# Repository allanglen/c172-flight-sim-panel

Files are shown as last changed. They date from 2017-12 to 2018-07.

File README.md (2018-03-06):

# Cessna 172 Skyhawk Flight Simulator Panel

 

I’m building a desk-mounted Cessna 172 flight simulator instrument panel for use as a training device in conjunction with real-world flight training. 

For details visit the project site at [https://cessna172sim.allanglen.com](https://cessna172sim.allanglen.com)

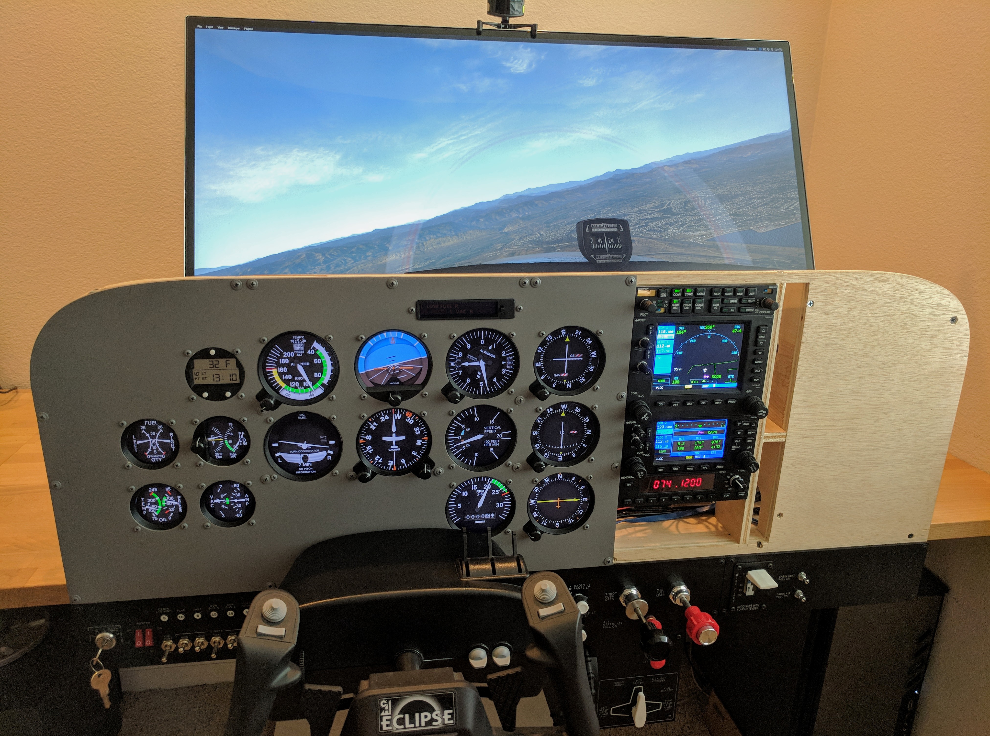
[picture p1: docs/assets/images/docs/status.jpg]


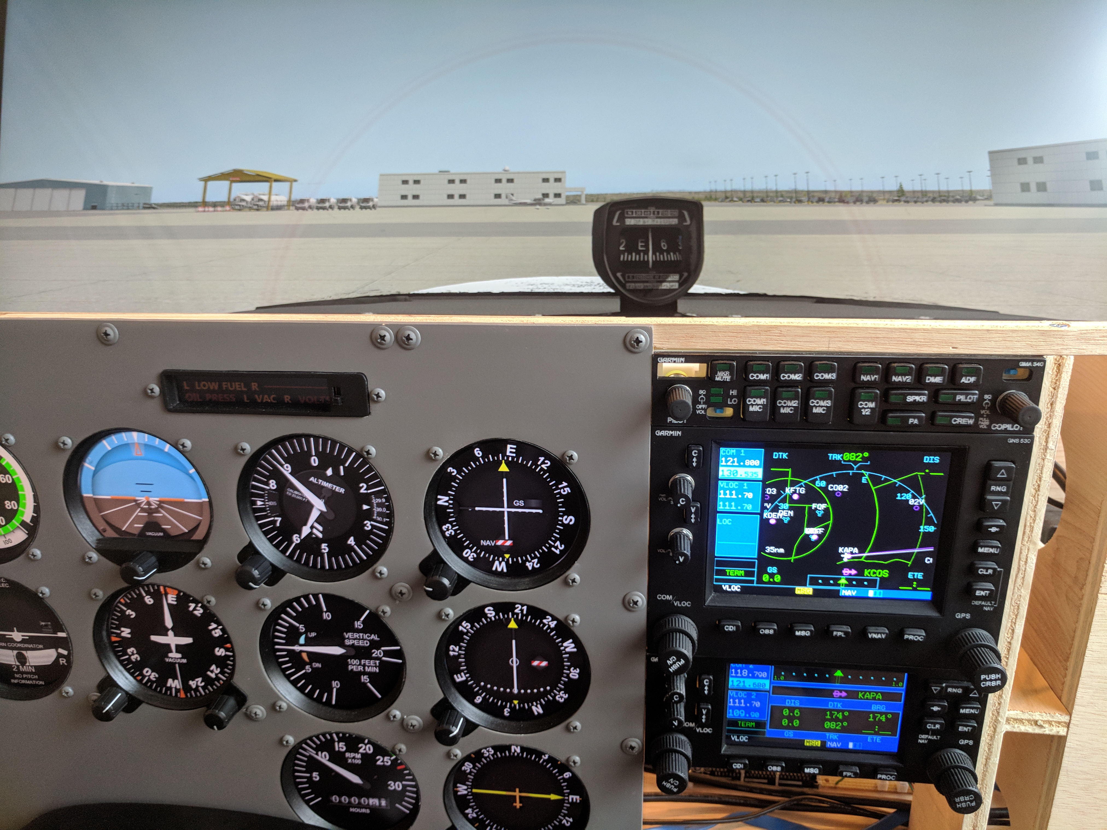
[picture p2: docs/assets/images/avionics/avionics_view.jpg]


latest

## License

Copyright 2018 Allan Glen

Licensed under the Apache License, Version 2.0 (the "License"); you may not use this file except in compliance with the License. You may obtain a copy of the License at

> <http://www.apache.org/licenses/LICENSE-2.0>

Unless required by applicable law or agreed to in writing, software distributed under the License is distributed on an "AS IS" BASIS, WITHOUT WARRANTIES OR CONDITIONS OF ANY KIND, either express or implied. See the License for the specific language governing permissions and limitations under the License.

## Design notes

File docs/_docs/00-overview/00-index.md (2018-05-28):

---
layout: single
title: Overview
permalink: /docs/
---
## Overview

I started this project to build a reasonably priced, desk-mounted, fully functional flight simulator panel that I could use as a training device in conjunction with real-world flight training.

In addition to using for flight training, building my own panel was a good excuse to start a new hardware project, add some new tools to my workbench (laser cutter), and learn more about aircraft subsystems and components along the way.

The content here primarily serves as a means to organize and document the project and to share it with the flight sim community.

This project is a work in progress and new content will be added as construction progresses.

{% include image.html file="status.jpg" %}

## Status

As of May 2018, the panel is in a flyable state with a fully operating [instrument panel](/docs/instrument-panel/), [switch panel](/docs/switch-panel/), [throttle/mixture controls](/docs/throttle-mixture-panel/), [flap control](/docs/flap-control-panel/), [trim wheel](/docs/trim-wheel), [parking brake](/docs/parking-brake), and [yoke](/docs/yoke-mount/).

I am currently working on the [avionics stack](/docs/avionics/). I have a working [Garmin GNS 530](/docs/avionics/garmin-gns-530/) and [Garmin GNS 430](/docs/avionics/garmin-gns-430), a partially functioning Garmin GMA 340 audio panel, and a fully functioning [Bendix-King KT76C Transponder](/docs/avionics/bendix-king-kt76c).

{% include image.html file="../avionics/avionics_view.jpg" %}

{% include image.html file="../avionics/avionics.jpg" %}

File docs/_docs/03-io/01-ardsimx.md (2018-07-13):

---
title: ArdSimX
permalink: /docs/io/ardsimx/
toc: false
---
# ArdSimX Interface

I use the excellent [ArdSimX Interface](http://simvim.com/ardsimx.html) to interface with X-Plane.

ArdSimX runs on inexpensive Arduino hardware and makes it simple to interface electrical components with X-Plane.

{% include image.html file="arduino_wiring.jpg" %}

I plan on upgrading to [SimVimCockpit](http://www.simvim.com/svcockpit.html) (aka ArdSimX 2.0) in the future to take advantage of multiplexers and allow for modular avionics but ArdSimX is working very well for my current needs.

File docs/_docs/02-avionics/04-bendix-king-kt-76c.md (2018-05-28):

---
title: Bendix King KT-76C
permalink: /docs/avionics/bendix-king-kt76c/
---
# Bendix King KT76C

The [Bendix King KT76C](https://bendixking.com/en/products/productitems/kt-76c) is a 4096 code mode C transponder with a design that is relatively simple to replicate.

I had originally intended to build a Garmin GTX 327 but sourcing an appropriate display proved challenging.

To simulate the KT76C I am using a MAX7219 8-digit 7-segment display that is easy to source and simple to integrate with Arduino.

{% include image.html file="bendix_king_kt76c_mounted.jpg" %}

{% include image.html file="bendix_king_kt76c_mounted_on.jpg" %}

## Parts List

{% include parts.html %}

## Main Assembly

The front of the unit is assembled by sandwiching three layers of acrylic together: the faceplate, the spacer (also used for mounting the 7-segment display), and the hardware mount (for mounting the buttons).

The following image was taken after the three layers were assembled and painted.

{% include image.html file="bendix_king_kt76c_layers.jpg" %}

### Faceplate

The faceplate is laser cut from white acrylic, painted black, and then laser engraved.

{% include svg.html file="faceplate.svg" %}

{% include image.html file="bendix_king_kt76c_faceplate.jpg" %}

### Spacer

The spacer provides a layer for mounting the 7-segment display. The thickness of the 
acrylic provided the perfect depth for mounting a thin layer of darkened plastic in front of the display (see Bezel below).

{% include svg.html file="spacer.svg" %}

{% include image.html file="bendix_king_kt76c_rear.jpg" %}

### Hardware Mount

The hardware mount provides a layer for mounting the push buttons. I used acrylic for mounting the push buttons to simplify construction and to avoid having to create a circuit board. The push buttons are glued into the hardware mount.

{% include svg.html file="hardware_mount.svg" %}

## Frame Mounts

The frame mounts are used to attach the assembly to the [frame](/docs/frame).

{% include image.html file="bendix_king_kt76c_side.jpg" %}

{% include svg.html file="left_frame_mount.svg" %}

{% include svg.html file="right_frame_mount.svg" %}

## Electronics Mount and Mounting Brackets

The electronics mount is used for attaching electronics and attaches the side mounts to the front assembly. The holes and slot are for attaching a multiplexer which I plan to convert to in the future to simplify wiring.

{% include svg.html file="electronics_mount.svg" %}

The 3d printed brackets are used to attach the components together as shown below.

{% include image.html file="bendix_king_kt76c_assembly.jpg" %}

{% include stl.html file="front_bracket.stl" thing=2933873 
   image="https://cdn.thingiverse.com/renders/67/5a/b3/0e/54/809f090a86a41fb306a07d19479f3988_preview_featured.jpg" %}
   
   {% include stl.html file="side_bracket.stl" thing=2933873 
      image="https://cdn.thingiverse.com/renders/8f/55/6f/31/b2/7cb270f7cf0b0fc12d74a7559b9151b3_preview_featured.jpg" %}

## Display Bezel

A 3d printed display bezel is inserted into the faceplate to hold a layer of darkened plastic in front of the display. The plastic layer hides the internals and provide the appearance of a larger display.

{% include stl.html file="bezel.stl" thing=2933873 
   image="https://cdn.thingiverse.com/renders/09/46/45/73/2a/6adf7d57c5af66891184265308b86544_preview_featured.jpg" %}

{% include image.html file="bendix_king_kt76c_display.jpg" %}

{% include image.html file="bendix_king_kt76c_display_bezel.jpg" %}

For the plastic cover, I cut a rectangle from a CD jewel case and applied a layer of darkened film to the underside.

{% include image.html file="bendix_king_kt76c_assembled.jpg" %}

## Mode Switch

The mode switch switches the transponder from between the off, standby, test, on, and altitude-reporting modes using a 5 position switch.

{% include image.html file="bendix_king_kt76c_mode_switch.jpg" %}

## Buttons

The buttons are 3d-printed from white PLA, painted, and laser-engraved. 

All of the buttons are the same size and the svg file contains a layer for each of the labels.

{% include svg.html file="button.svg" %}

{% include stl.html file="display_bezel.stl" thing=2933873 
   image="https://cdn.thingiverse.com/renders/6c/10/b4/38/b0/fd9e4b077ecdf45762ce9707d49869b7_preview_featured.jpg" %}

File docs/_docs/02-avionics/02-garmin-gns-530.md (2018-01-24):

---
title: Garmin GNS 530
permalink: /docs/avionics/garmin-gns-530/
---
# Garmin GNS 530

The [Garmin GNS 530](https://buy.garmin.com/en-US/US/p/119) has a larger, higher-resolution display than the smaller [Garmin 430](/docs/avionics/garmin-gns-430). Both are no longer in production but continue to be very common in general aviation aircraft.

This GPS is specifically designed for use with X-Plane 11.10 (or greater) and uses the [screen-only popup instrument window](https://developer.x-plane.com/2017/09/three-lesser-known-aircraft-features-for-11-10/) feature to render the GPS screen on an HDMI display that is integrated into the assembly.

{% include image.html file="garmin_gns_530_map.jpg" %}

{% include image.html file="garmin_gns_530_airports.jpg" %}

{% include image.html file="garmin_gns_530_mounted_right_view.jpg" %}

## Parts List

{% include parts.html %}

## Faceplate

The faceplate is laser cut from white acrylic, painted black, and then laser engraved.

{% include svg.html file="faceplate.svg" %}

## Hardware Mount

The hardware mount provides a layer for mounting the push-buttons and the display. I used acrylic for mounting the push buttons to simplify construction and to avoid having to create a circuit board. The push buttons are glued into the hardware mount.

{% include svg.html file="hardware_mount.svg" %}

## Frame Mounts

The frame mounts are used to attach the assembly to the [frame](/docs/frame).

{% include image.html file="frame_mount_left.jpg" %}

{% include svg.html file="frame_mount_left.svg" %}

{% include svg.html file="frame_mount_right.svg" %}

### Frame Mount Brackets

The frame mounts are attached to the hardware mount with these brackets and \#4 x 1/2" flat head screws.

{% include stl.html file="display_mounting_clips.stl" thing=2764205 
   image="https://cdn.thingiverse.com/renders/c6/3f/43/48/b0/d1ef4514cb0441461229379ad1ca340c_preview_featured.jpg" %}
   
The frame mounts also secure the display to the hardware mount and to the faceplate. A shallow 1/8" hole is drilled into the rear of the faceplate. The clips are designed to work with \#6-32 x 1/2 pan head screws.

{% include image.html file="hardware_mount.jpg" %}

{% include image.html file="garmin_gns_530_off.jpg" %}

### Electronics Mount

The electronics mount is used to attach the display electronics (HDMI controller board) and IO multiplexers to the assembly (more on the wiring coming soon).

{% include svg.html file="electronics_mount.svg" %}

Two 3d printed blocks are used for attaching the acrylic electronics mount to the frame mount brackets. The parts are attached with \#4 x 1/2" flat head screws.

{% include stl.html file="display_electronics_mount_block.stl" thing=2764205 
   image="https://cdn.thingiverse.com/renders/3b/c3/ea/1a/80/05e5d92b41b487360761c2e1b10e862a_preview_featured.jpg" %}

{% include image.html file="electronics_mount.jpg" %}

{% include image.html file="electronics_mount_zoom.jpg" %}

### Display Bezel

A 3d printed display bezel frames the active pixels on the display is similar to the bezel profile on a real GNS 530.

{% include stl.html file="display_bezel.stl" thing=2764205 
   image="https://cdn.thingiverse.com/renders/c4/ef/45/e5/b0/6adf7d57c5af66891184265308b86544_preview_featured.jpg" %}

{% include image.html file="garmin_gns_530_bezel.jpg" %}

## Buttons

The GPS buttons are 3d-printed from white PLA, painted, and laser-engraved.

### Small Buttons

{% include svg.html file="button_small_engrave.svg" %}

### Medium Buttons

{% include svg.html file="button_medium_engrave.svg" %}

### Zoom Button

{% include svg.html file="button_zoom_engrave.svg" %}

### Flip Flop Buttons

{% include svg.html file="button_medium_vertical_engrave.svg" %}

## Knobs

### Dual-Rotary Knobs

The knobs for the dual concentric rotary encoders are designed to match those found on a real GNS 530 and are 3d printed from white PLA, painted, and laser-engraved.

{% include stl.html file="knob_inner.stl" thing=2764205 
   image="https://cdn.thingiverse.com/renders/a4/0d/92/bc/c6/16d938061b9438ff41fe295429974ba8_preview_featured.jpg" %}

{% include stl.html file="knob_outer.stl" thing=2764205 
   image="https://cdn.thingiverse.com/renders/dd/38/54/c6/78/aeeb571b9cadac25ff907b3bd9abecea_preview_featured.jpg" %}

{% include svg.html file="knob_engrave.svg" %}

### Volume Knobs

The knob is 3d printed from white PLA, painted, and laser-engraved.

{% include stl.html file="volume_knob.stl" thing=2764205 
   image="https://cdn.thingiverse.com/renders/e1/85/6a/1f/8b/1576670b45151153a2681a1a933a3951_preview_featured.jpg" %}

{% include svg.html file="knob_volume_engrave.svg" %}

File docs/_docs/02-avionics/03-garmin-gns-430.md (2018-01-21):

---
title: Garmin GNS 430
permalink: /docs/avionics/garmin-gns-430/
---
# Garmin GNS 430

The [Garmin GNS 430](https://buy.garmin.com/en-US/US/p/82) is no longer in production but it continues to be ubiquitous in general aviation. 

This GPS is specifically designed for use with X-Plane 11.10 (or greater) and uses the [screen-only popup instrument window](https://developer.x-plane.com/2017/09/three-lesser-known-aircraft-features-for-11-10/) feature to render the GPS screen on an HDMI display that is integrated into the assembly.

{% include image.html file="garmin_gns_430.jpg" %}

{% include image.html file="garmin_gns_430_face.jpg" %}

{% include image.html file="garmin_gns_430_mounted.jpg" %}

## Parts List

{% include parts.html %}

## Faceplate

The faceplate is laser cut from white acrylic, painted black, and then laser engraved.

{% include svg.html file="faceplate.svg" %}

## Hardware Mount

The hardware mount provides a layer for mounting the push-buttons and the display. I used acrylic for mounting the push buttons to simplify construction and to avoid having to create a circuit board. The push buttons are glued into the hardware mount.

{% include image.html file="hardware_mount.jpg" %}

{% include svg.html file="hardware_mount.svg" %}

## Frame Mounts

The frame mounts are used to attach the assembly to the [frame](/docs/frame).

{% include image.html file="frame_mount.jpg" %}

{% include svg.html file="frame_mount_left.svg" %}

{% include svg.html file="frame_mount_right.svg" %}

## Frame Mount Brackets

The frame mounts are attached to the hardware mount with these brackets and \#4 x 1/2" flat head screws.

{% include stl.html file="frame_mount_bracket.stl" thing=2723972 
   image="https://cdn.thingiverse.com/renders/ae/25/b3/8c/20/65588325c66414b8cad46b8dff0e5aac_preview_featured.jpg" %}

### Display Mounting Clips

The display mounting clips secure the display to the hardware mount and to the faceplate. A shallow 1/8" hole is drilled into the rear of the faceplate. The clips are designed to work with \#6-32 x 1/2 pan head screws.

{% include image.html file="hardware.jpg" %}

{% include stl.html file="display_clip.stl" thing=2723972 
   image="https://cdn.thingiverse.com/renders/c9/98/23/45/53/2f104f44852b66ed3ddcea2a0592f77d_preview_featured.jpg" %}

{% include image.html file="display_rear.jpg" %}

### Display Bezel

A 3d printed display bezel is sandwiched between the layers to compensate for the difference in thickness between the display and the hardware mount panel. The bezel provides a clean finish and is similar to the bezel profile on a real GNS 430.

{% include stl.html file="display_bezel.stl" thing=2723972 
   image="https://cdn.thingiverse.com/renders/da/1e/f0/b8/a8/6adf7d57c5af66891184265308b86544_preview_featured.jpg" %}

## Buttons

The GPS buttons are 3d-printed from white PLA, painted, and laser-engraved.

### Small Buttons

{% include svg.html file="button_small_engrave.svg" %}

### Medium Buttons

{% include svg.html file="button_medium_engrave.svg" %}

### Zoom Button

{% include svg.html file="button_zoom_engrave.svg" %}

### Flip Flop Buttons

{% include svg.html file="button_medium_vertical_engrave.svg" %}

## Knobs

### Dual-Rotary Knobs

The knobs for the dual concentric rotary encoders are designed to match those found on a real GNS 430 and are 3d printed from white PLA, painted, and laser-engraved.

{% include image.html file="knob.jpg" %}

{% include stl.html file="knob_inner.stl" thing=2723972 
   image="https://cdn.thingiverse.com/renders/e3/bb/47/3b/b4/16d938061b9438ff41fe295429974ba8_preview_featured.jpg" %}

{% include stl.html file="knob_outer.stl" thing=2723972 
   image="https://cdn.thingiverse.com/renders/95/8a/1e/81/d2/aeeb571b9cadac25ff907b3bd9abecea_preview_featured.jpg" %}

{% include svg.html file="knob_engrave.svg" %}

### Volume Knobs

The knob is 3d printed from white PLA, painted, and laser-engraved.

{% include stl.html file="volume_knob.stl" thing=2723972 
   image="https://cdn.thingiverse.com/renders/67/da/7a/8f/81/1576670b45151153a2681a1a933a3951_preview_featured.jpg" %}

{% include svg.html file="knob_volume_engrave.svg" %}

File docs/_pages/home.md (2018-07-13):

---
layout: splash
permalink: /
header:
  overlay_color: "#5e616c"
  overlay_image: /assets/images/hero.jpg
  overlay_filter: 0.2
  cta_label: "<i class='fas fa-book'></i> Details"
  cta_url: "/docs/"
excerpt: >-
  Design files, 3d models, wiring diagrams, and code artifacts for building a Cessna 172 Skyhawk flight simulator.<br /><br />
  {::nomarkdown}
  <iframe style="display: inline-block;" src="https://ghbtns.com/github-btn.html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" frameborder="0" scrolling="0" width="160px" height="30px"></iframe>
  <iframe style="display: inline-block;" src="https://ghbtns.com/github-btn.html?user=allanglen&repo=c172-flight-sim-panel&type=star&count=true&size=large" frameborder="0" scrolling="0" width="158px" height="30px"></iframe>
  {:/nomarkdown}
feature_row:
  - image_path: /assets/images/highlight-instrument-panel.jpg
    alt: "steam gauge panel"
    title: "Steam Gauge Panel"
    excerpt: >-
      I opted to build a [steam gauge panel](/docs/instrument-panel) to support training with traditional instruments.<br/><br/>
      The gauges are software rendered on a display with physical interaction provided through hardware controls.
    url: "/docs/instrument-panel/"
    btn_class: "btn--primary"
    btn_label: "Details"
  - image_path: /assets/images/highlight-avionics.jpg
    alt: "avionics stack"
    title: "Avionics Stack"
    excerpt: >-
      I'm building a complete [avionics stack](/docs/avionics) with an audio panel, GPS (GNS530 and GNS430), transponder, and auto-pilot.
    url: "/docs/avionics/"
    btn_class: "btn--primary"
    btn_label: "Details"
  - image_path: /assets/images/highlight-switch-panel.jpg
    alt: "X-Plane compatible"
    title: "X-Plane Compatible"
    excerpt: >-
      The hardware here is designed to work with [X-Plane 11](http://www.x-plane.com/) and is interfaced using [ArdSimX](http://www.simvim.com/ardsimx.html).<br/><br/>
      It should also be possible to use this hardware with other flight sims (FSX, P3D) via [FSUIPC](http://www.schiratti.com/dowson.html).
    url: "/docs/io/ardsimx/"
    btn_class: "btn--primary"
    btn_label: "Details"
intro:
  - excerpt: >-
      I'm building a desk-mounted Cessna 172 flight simulator instrument panel for use as a training device in conjunction with real-world flight training.
      <br/><br/>
      This project is very much a [work in progress](/docs#status) and I'll be adding new content over time.
---

{% include feature_row id="intro" type="center" %}

{% include feature_row %}

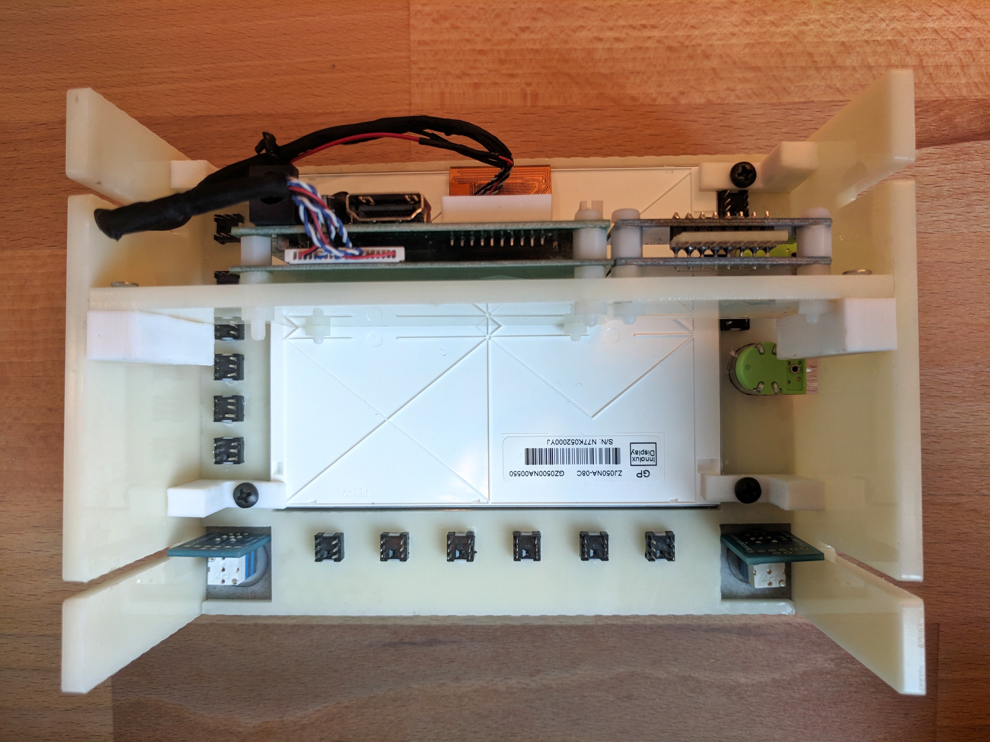
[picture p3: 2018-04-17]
docs/assets/images/garmin-gns-530/hardware_mount.jpg

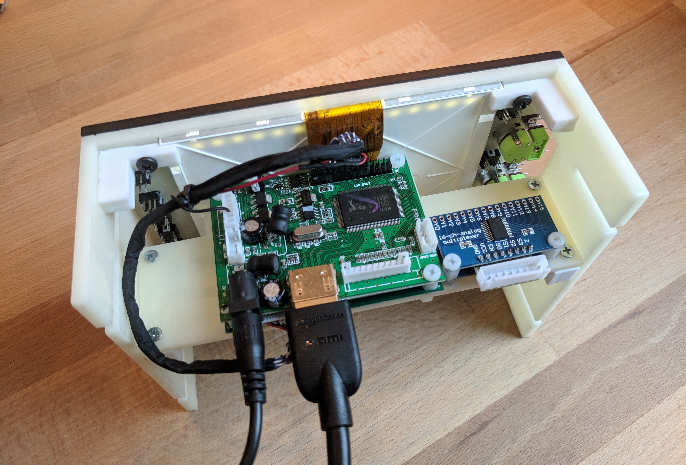
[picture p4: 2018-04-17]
docs/assets/images/garmin-gns-530/electronics_mount.jpg

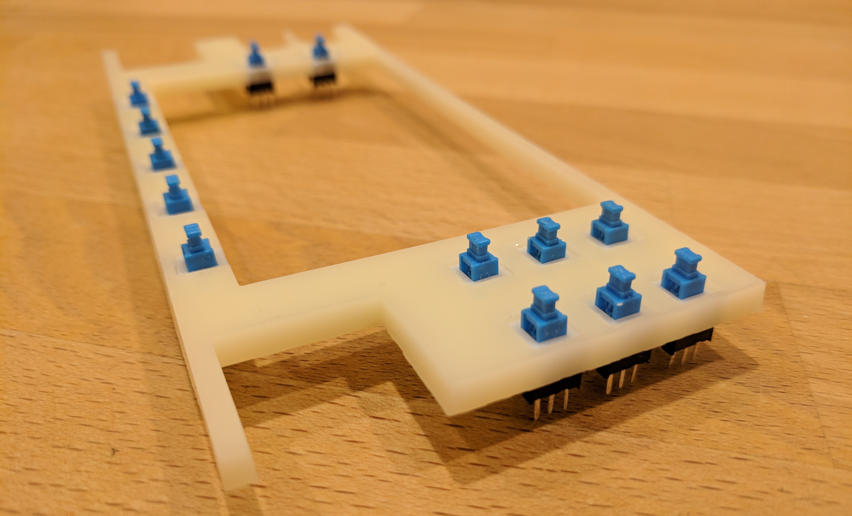
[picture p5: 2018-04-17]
docs/assets/images/garmin-gns-430/hardware_mount.jpg

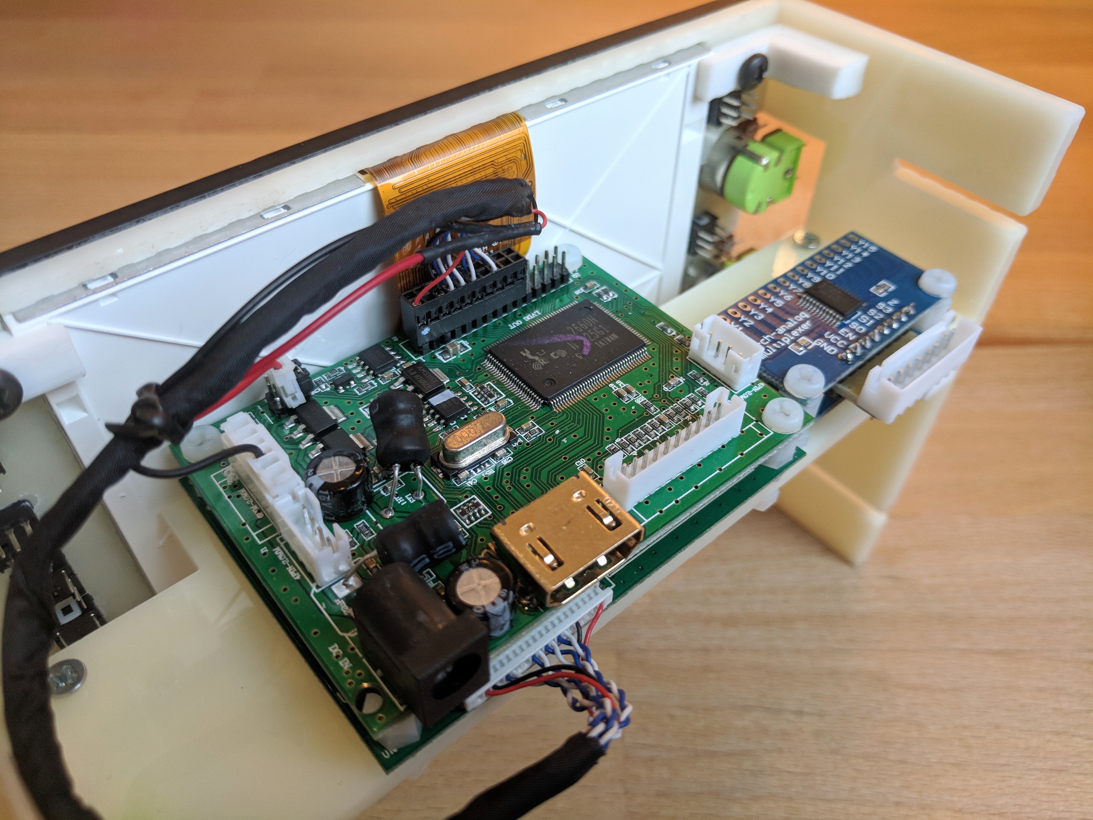
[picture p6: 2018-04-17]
docs/assets/images/garmin-gns-530/electronics_mount_zoom.jpg

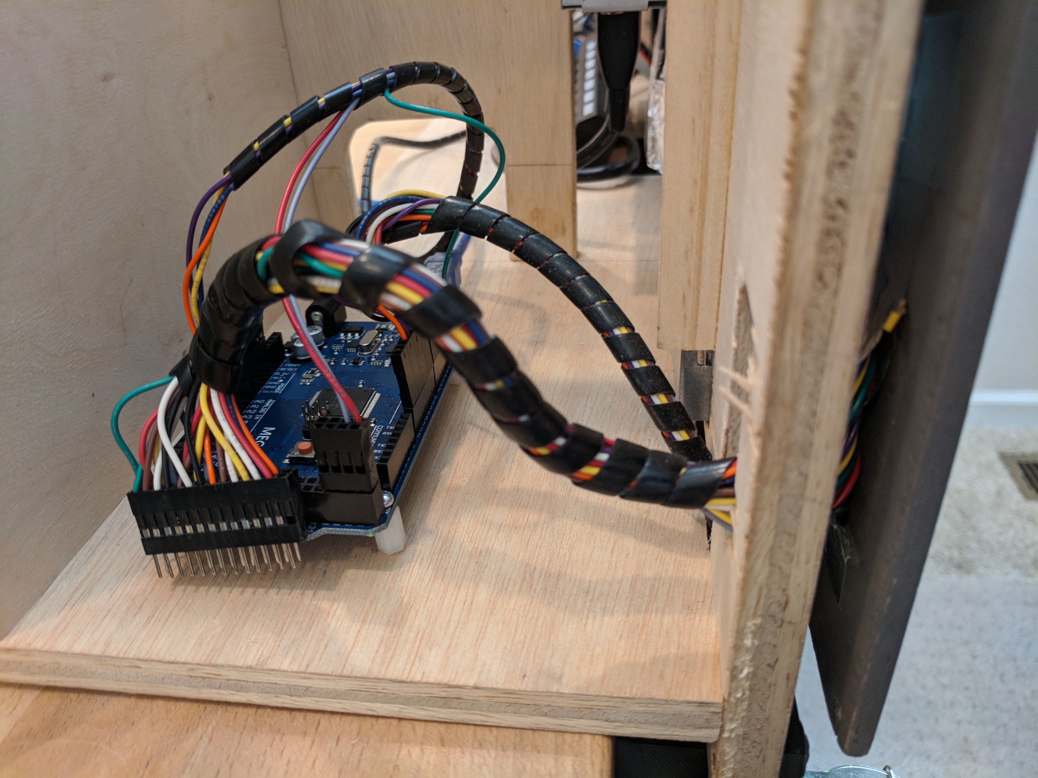
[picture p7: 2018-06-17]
docs/assets/images/instrument-panel/panel_attach_03.jpg

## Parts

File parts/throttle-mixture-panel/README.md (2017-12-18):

# Throttle and Mixture Panel

The throttle and mixture panel houses real Cessna 172 throttle and mixture controls, lighting rheostats, and the alt static air switch.

The panel is attached directly to the frame with truss-head screws.

throttle_mixture_panel

## Panel

The panel is laser cut from white acrylic, painted black, and then laser engraved.

`throttle_mixture_panel.svg`

throttle_mixture_panel

## Light Dimming Rheostat Knobs

The panel lighting rheostat knobs are 3d-printed and mounted on dual-concentric linear potentiometers.

rheostat_knobs

### Inner Knob

`rheostat_knob_inner.stl` (https://www.thingiverse.com/thing:2720361)

rheostat_knob_inner

### Outer Knob

`rheostat_knob_outer.stl` (https://www.thingiverse.com/thing:2720361)

rheostat_knob_outer

## Bonus: Throttle and Mixture Knobs

I have created models of the throttle and mixture knobs using dimensions from the genuine parts as I was unable to find actual dimensions for these components online when I was looking initially. These might be of use in your project if you prefer to make your own controls.

### Throttle Knob

`throttle_knob.stl` (https://www.thingiverse.com/thing:2720409)

throttle_knob

### Mixture Knob.

`mixture_knob.stl` (https://www.thingiverse.com/thing:2720409)

mixture_knob.stl

`mixture_button.stl` (https://www.thingiverse.com/thing:2720409)

mixture_button

## Parts List

| Component | Part | Quantity  | Source |
| --- | --- | --- | --- |
| Panel | 3/16" bright white cast acrylic | 310x104mm | http://ebay.to/2Bn1CMs |
| Rheostat | Dual-concentric linear potentiometer | 2 | http://amzn.to/2CNa5ZA |
| Throttle Control | A-820 FRICTION LOCK CONTROL | 1 | https://www.aircraftspruce.com/catalog/appages/a820.php |
| Mixture Control  | A-790 VERNIER CONTROL - RED | 1 | https://www.aircraftspruce.com/catalog/appages/a7902.php |
| Alt Static Air | Chrome Push/Pull Switch | 1 | http://www.desktopaviator.com/Products/parts.htm |

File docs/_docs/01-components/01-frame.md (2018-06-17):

---
title: Frame
permalink: /docs/frame/
toc: false
---
# Frame

I sketched out some general plans and key dimensions before building the frame but I built the support structure and cut-outs by measuring and modifying as I went. 

As a result, I don't have a single set of dimensional drawings of the frame yet but I plan on getting that documented and posted.

The image below is a work-in-progress photo from several months ago and several modifications have been made since.

More on this coming soon..

{% include image.html file="frame.jpg" %}

## Layout

The physical dimensions of the display required some adjustments from the actual layout of a Cessna 172 but I have attempted to keep the dimensions as close to actual as possible. The panel is about 6 inches narrower than an actual Cessna panel to save space.

The shaft of the yoke moves parallel to the desk surface just below the LCD monitor and just above the surface of the desk. This keeps the yoke reasonably close to the correct height from the top of the glareshield and allows me to fit a mostly unmodified {% include part.html id="yoke" %} into the panel.

The portion of the frame below the desk surface houses the switch panel, throttle/mixture controls, flaps controls, and trim wheel.

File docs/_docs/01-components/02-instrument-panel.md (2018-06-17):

---
title: Instrument Panel
permalink: /docs/instrument-panel/
---

# Instrument Panel

The instrument panel simulates the typical setup in a steam gauge Cessna 172. I opted to build a steam gauge panel to support training with traditional instruments.

The instrument panel is comprised of a layer of hardware that is mounted over a 23" HDMI display.

{% include image.html file="instrument_panel.jpg" %}

The instruments are rendered with [Air Manager](https://www.siminnovations.com/). I have made some minor customizations but most of the instruments that I am using are provided either by Sim Innovations or the community.
                                                                            
{% include image.html file="instrument_display.jpg" %}

## Parts List

{% include parts.html %}

## Display

I use a 23" display (I had an unused Acer V233H lying around) to render the instruments behind the hardware panel. The display is stripped down (case removed) and is mounted directly into the [frame](/docs/frame/).

{% include image.html file="display_01.jpg" %}

The display is mounted as close to the left as possible given the curve of the glare shield.

{% include image.html file="display_02.jpg" %}

The display is set into the frame and held in place by a [panel](#panel) that is mounted to the frame.

{% include image.html file="display_03.jpg" %}

{% include image.html file="display_04.jpg" %}

{% include image.html file="display_05.jpg" %}

## Panel

The instrument panel is constructed from painted 1/4" inch birch plywood with cutouts for mounting instrument [bezels](#bezels) and hardware.

{% include image.html file="panel_01.jpg" %}

{% include image.html file="panel_02.jpg" %}

{% include image.html file="panel_03.jpg" %}

The electrical components (rotary encoders, buttons, and switches) mount into the rear of the bezels and the wiring is routed via channels cut in the back of the plywood. The channels were cut using a {% include part.html id="dremel" label="Dremel" %} with a router bit.

{% include image.html file="panel_rear_01.jpg" %}

{% include image.html file="panel_rear_02.jpg" %}

{% include image.html file="panel_rear_03.jpg" %}

{% include image.html file="panel_rear_04.jpg" %}

{% include image.html file="panel_rear_05.jpg" %}

{% include image.html file="panel_rear_06.jpg" %}

The wiring bundle is passed through a cutout in the frame and connected to an {% include part.html id="arduino_mega" %}.

{% include image.html file="wiring_routing_01.jpg" %}

{% include image.html file="panel_attach_03.jpg" %}

All parts for the panel are designed to fit into the depth of the panel, allowing the bezels to fit flush against the display.

{% include image.html file="panel_attach_01.jpg" %}

{% include image.html file="panel_attach_02.jpg" %}

{% include image.html file="panel_attach_04.jpg" %}

{% include image.html file="panel_attached_02.jpg" %}

{% include image.html file="panel_attached_01.jpg" %}

## Bezels

The instrument bezels are 3d printed and designed to allow the hardware to be mounted cleanly into the panel. The holes in the plywood were cut using a {% include part.html id="hole_saw_3_125" label='3 1/8" hole saw' %}.

{% include image.html file="bezel_lcd.jpg" %}

{% include image.html file="bezels_installed.jpg" %}

A router guide was designed and 3d printed to cut out the bezel tabs using a flush trim router bit.

{% include stl.html file="bezel_large_router_guide.stl" thing=2690541 
    image="https://cdn.thingiverse.com/renders/63/3c/b3/56/f5/6fda26d00e11bedbcd7b14600c7b7b00_preview_featured.jpg" %}

### Large Instruments (3 1/2")

#### Tachometer, turn and balance indicator
{% include stl.html file="bezel_large.stl" thing=2690541 
   image="https://cdn.thingiverse.com/renders/f5/dd/02/7e/b4/bcd29e43e508982c7a6248004207fe23_preview_featured.jpg" %}

#### Airspeed indicator, altimeter, vsi, vor, adf

{% include stl.html file="bezel_large_single_encoder.stl" thing=2690541 
   image="https://cdn.thingiverse.com/renders/ad/56/ee/d8/c5/c8274b04c022eb560f5eb3016d9ff824_preview_featured.jpg" %}

#### Gyro compass

{% include stl.html file="bezel_large_dual_encoder.stl" thing=2690541 
   image="https://cdn.thingiverse.com/renders/57/70/aa/95/02/4f2366d3d5626a22a1b49f78964c66ce_preview_featured.jpg" %}
   
#### Attitude indicator

{% include stl.html file="bezel_large_attitude.stl" thing=2690541 
   image="https://cdn.thingiverse.com/renders/3e/a3/57/92/ad/e1817d9e19f8f73877e49e1d126848e1_preview_featured.jpg" %}

### Small Instruments (2 1/4")

#### vacuum/ammeter, fuel quantity, engine temp/press.
{% include stl.html file="bezel_small.stl" thing=2690541 
   image="https://cdn.thingiverse.com/renders/7e/19/b4/fa/40/a7908e04e2fe741fddfd757d57ce99ea_preview_featured.jpg" %}

#### EGT/fuel flow

{% include stl.html file="bezel_small_egt.stl" thing=2690541 
   image="https://cdn.thingiverse.com/renders/c6/26/eb/45/5e/18b6e8353e04c0a28694485bd8a7e288_preview_featured.jpg" %}

#### Clock

{% include stl.html file="bezel_small_clock.stl" thing=2690541 
   image="https://cdn.thingiverse.com/renders/6c/ef/02/de/13/85495e42e1ecd52ded2b2a4fdee56f2b_preview_featured.jpg" %}
   
#### Clock buttons

{% include stl.html file="bezel_small_clock_button.stl" thing=2690541 
   image="https://cdn.thingiverse.com/renders/2a/9c/08/7f/c1/aa12695fb33f248eabd996570ed714c9_preview_featured.jpg" %}

### Annunciators

{% include stl.html file="bezel_annunciator.stl" thing=2690541 
   image="https://cdn.thingiverse.com/renders/b6/18/b7/cd/bf/ea642fa15b62c3cd30a555506e826603_preview_featured.jpg" %}

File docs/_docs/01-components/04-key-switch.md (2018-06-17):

---
title: Key Switch
permalink: /docs/key-switch/
---
# 5 Position Spring-Return Key Switch

This key switch simulates the 5 positions on a standard Cessna 172 ignition switch (off, right magneto, left magneto, both, and start) and provides a spring return from the start position.

{% include image.html file="key_switch.jpg" %}

The switch is assembled from a 3d printed mount, a filing cabinet lock, and a 5 position rotary switch.

{% include image.html file="key_switch_animation.gif" %}

## Parts List

{% include parts.html %}

## Assembly

The components of the key switch are mounted into a 3d printed mount that allows a cabinet lock to be attached to a rotary switch and the cabinet lock arm to engage a spring when moved into the start position.

{% include stl.html file="key_switch.stl" thing=2687594 
   image="https://cdn.thingiverse.com/renders/5a/88/6d/c2/59/c6c4b9057df0631dab33539f41e4be01_preview_featured.jpg" %}

The rotary encoder is mounted into the small hole and the cabinet lock is pressed through the [panel](../) and into the large hole.

Some modifications must be made to the cabinet lock to allow the shaft of the rotary encoder to be securely attached:

1. Drill out the screw hole in the cabinet lock body to allow the shaft of the rotary encoder to be inserted snugly into the body of the lock. A washer or two may be needed to ensure the bar on the cabinet lock is securely fitted over the square mount on the cabinet lock body.
2. Drill a hole in the side of the cabinet lock body and tap it to allow a hex set screw to be secured against the rotary encoder shaft. A hole must also be made in the cabinet lock barrel to allow access to the set screw
3. Remove the rotational stop from the cabinet lock barrel. This design uses the stops of the rotary switch instead.

The key switch when assembled and mounted into the [panel](/docs/switch-panel/):

{% include image.html file="key_switch_mounted.jpg" %}

For wiring details, see [http://www.simvim.com/asx_wire.html](http://www.simvim.com/asx_wire.html). I used parallel 2k resistors as I did not have any 1k resistors in my parts bin.

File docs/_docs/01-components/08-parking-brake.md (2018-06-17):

---
title: Parking Brake
permalink: /docs/parking-brake/
toc: false
---
# Parking Brake

Work in progress

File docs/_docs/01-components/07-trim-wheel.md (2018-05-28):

---
title: Motorized Trim Wheel
permalink: /docs/trim-wheel/
toc: false
---
# Motorized Trim Wheel

I designed the trim wheel to be able to be motorized (for movement when autopilot is engaged). 

The fuel selector control is built into the center column as my panel is designed to be desk-mounted and is not connected to the floor.

More documentation coming on this..

{% include image.html file="trim_wheel_column.jpg" %}

{% include image.html file="trim_wheel_faceplate.jpg" %}

{% include image.html file="trim_wheel_close.jpg" %}

{% include image.html file="fuel_selector.jpg" %}

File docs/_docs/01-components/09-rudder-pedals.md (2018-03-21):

---
title: Rudder Pedals
permalink: /docs/rudder-pedals/
toc: true
---
# Rudder Pedals

I use [MFG Crosswind Rudder Pedals](http://mfg.simundza.com/products) for rudder control in X-Plane.

The Crosswinds are impressively well-built rudder pedals but the pedal style that is provided does not allow the typical heel-on-the-floor position that would normally be used in a Cessna 172.

These pedals are similar in design to real Cessna 172 pedals, allowing a heel-on-the-floor position during flight and allowing toe-braking during taxi.

{% include image.html file="rudder_pedals.jpg" %}

{% include image.html file="rudder_pedal_left.jpg" %}

{% include image.html file="rudder_pedal_right.jpg" %}

The pedals are designed to be attached the existing Crosswind pedal mounts and installation is quick and easy. The Crosswind pedals should be adjusted to the steepest angle.

{% include image.html file="rudder_pedal_rear.jpg" %}

I also adjusted the brake tension spring to its lowest resistance setting.

## Pedals

{% include stl.html file="rudder_pedal_left.stl" thing=2830791 
   image="https://cdn.thingiverse.com/renders/27/34/95/28/d9/441d9cf7476752a1c6c116dc8ba024fd_preview_featured.jpg" %}
   
{% include stl.html file="rudder_pedal_right.stl" thing=2830791 
   image="https://cdn.thingiverse.com/renders/8f/16/2c/53/05/c16307fcefbfb488b3e6639ca616b63c_preview_featured.jpg" %}

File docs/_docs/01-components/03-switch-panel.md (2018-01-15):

---
title: Switch Panel
permalink: /docs/switch-panel/
assets: /assets/images/c172/switch-panel/
---

# Switch Panel

The switch panel simulates a typical setup in a steam gauge Cessna 172. The panel houses a custom-built spring-return [key switch](#key-switch), simulated [fuses](#fuses), and toggle switches for the electrical buses, fuel pump, lighting, pitot heat, and avionics.

The panel is attached directly to the [frame](/docs/frame) with truss-head screws.

{% include image.html file="switch_panel.jpg" %}

## Parts List

{% include parts.html %}

## Panel

The panel is laser cut from white acrylic, painted black, and then laser engraved.

{% include svg.html file="switch_panel.svg" %}

## Key Switch

A 5-position, spring-action key switch is mounted into the panel. See [key switch](/docs/key-switch/) for build details.

{% include image.html file="../key-switch/key_switch.jpg" %}

## Fuses

DPDT buttons with 3d-printed caps are mounted into the panel to simulate resettable fuses. 

The 3d printed caps are printed in white PLA, painted black, and then laser engraved to indicate the amperage of the fuse.

{% include image.html file="fuses.jpg" %}

### Fuse Button Caps

The button caps are 3d printed from white PLA, painted black, and then laser engraved.

{% include stl.html file="fuse_button.stl" thing=2687618 
   image="https://cdn.thingiverse.com/renders/3c/79/9f/93/58/8043766332737adb9f48f97e9710d479_preview_featured.jpg" %}

The fuse amperage is laser-engraved after painting the button cap. The SVG has layers that can be toggled for the various fuse values.

{% include svg.html file="fuse_button.svg" %}

A guide was created for aligning the button cap in the laser cutter.

{% include stl.html file="fuse_button_guide.stl" thing=2687618 
   image="https://cdn.thingiverse.com/renders/16/ec/19/91/be/9735bf68ed6df133222ff3eddd02ccf2_preview_featured.jpg" %}
   
## Fuse Button Mounts

The fuse switches are mounted to the back of the panel by gluing the switches into laser-cut acrylic strips.

{% include image.html file="fuse_mount.jpg" %}

{% include svg.html file="fuse_button_mount_top.svg" %}

{% include svg.html file="fuse_button_mount_right.svg" %}

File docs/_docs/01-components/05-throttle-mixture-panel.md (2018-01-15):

---
title: Throttle/Mixture Panel
permalink: /docs/throttle-mixture-panel/
---
# Throttle and Mixture Panel

The throttle and mixture panel houses genuine Cessna 172 throttle and mixture controls, lighting rheostats, and the alt static air switch.

The panel is attached directly to the frame with truss-head screws.

{% include image.html file="throttle_mixture_panel.jpg" %}

## Parts List

{% include parts.html %}

## Panel

The panel is laser cut from white acrylic, painted black, and then laser engraved.

{% include svg.html file="throttle_mixture_panel.svg" %}

## Light Dimming Rheostat Knobs

The panel lighting rheostat knobs are 3d-printed and mounted on dual-concentric linear potentiometers.

{% include image.html file="rheostat_knobs.jpg" %}

### Inner Knob

{% include stl.html file="rheostat_knob_inner.stl" thing=2720361 
   image="https://cdn.thingiverse.com/renders/4a/37/67/06/8c/59cbb05dc2ce480d777022dc08935a1f_preview_featured.jpg" %}

### Outer Knob

{% include stl.html file="rheostat_knob_outer.stl" thing=2720361 
   image="https://cdn.thingiverse.com/renders/84/6b/cf/14/e3/86aa6afae2077783c5d2bf1382fe7182_preview_featured.jpg" %}
   
## Bonus: Throttle and Mixture Knobs

I have created models of the throttle and mixture knobs using dimensions from genuine parts as I was unable to find actual dimensions for these components online when I was looking initially.

These might be of use in your project if you prefer to make your own controls.

### Throttle Knob

{% include stl.html file="throttle_knob.stl" thing=2720384 
   image="https://cdn.thingiverse.com/renders/93/82/3a/ef/70/8f6060933ee6a448bd675883ccd13b37_preview_featured.jpg" %}

### Mixture Knob.

{% include stl.html file="mixture_knob.stl" thing=2720409 
   image="https://cdn.thingiverse.com/renders/a1/ee/ee/52/35/fc76f6bd6fe40596e0d6cb994e3da4bf_preview_featured.jpg" %}

{% include stl.html file="mixture_button.stl" thing=2720409 
   image="https://cdn.thingiverse.com/renders/7d/7e/5c/1e/b8/063385e9dfe6df3df86d8f013b779b52_preview_featured.jpg" %}

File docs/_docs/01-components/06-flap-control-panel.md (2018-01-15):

---
title: Flap Control Panel
permalink: /docs/flap-control-panel/
---
# Flap Control Panel

The flap control panels houses a custom-built electronic flap control and the cabin heat and cabin air switches.

The flap control assembly includes a servo-actuated flap position indicator that tracks the position of the flaps in the sim.

{% include image.html file="flaps_panel.jpg" %}

## Parts List

{% include parts.html %}

## Panel

The panel is laser cut from white acrylic, painted black, and then laser engraved. The panel is attached directly to the frame with truss-head screws.

{% include svg.html file="flap_panel.svg" %}

## Flap Control

The flap control is constructed from a combination of 3d printed and laser-cut parts and uses a genuine Cessna 172 flaps lever that I found for cheap on eBay.

### Frame

The frame provides the structure for the assembly and the mounts for the electrical components.

The sides of the frame were cut from acrylic to reduce construction time but the side panels could also be 3d printed. I have included .stl files for the frame sides if you choose to print them. 

I used 25mm M3 nylon hex spacers to secure the frame sides at the rear of the assembly.

{% include image.html file="flaps_frame.jpg" %}

{% include image.html file="flap_lever_mount_rear.jpg" %}

#### Frame Left Panel

The left side of the frame is used to mount the servo for the flaps position indicator.

{% include svg.html file="flap_frame_left.svg" %}

{% include stl.html file="flap_frame_left.stl" thing=2722523 
   image="https://cdn.thingiverse.com/renders/3d/78/b2/d0/64/38217c8ac11dd7c0b040bb87404aada8_preview_featured.jpg" %}
  
#### Frame Right Panel

The right side of the frame is used to mount the potentiometer to which the position indicator is attached.

{% include svg.html file="flap_frame_right.svg" %}

{% include stl.html file="flap_frame_right.stl" thing=2722523 
   image="https://cdn.thingiverse.com/renders/14/fb/ab/3b/8a/621ee3263bb3322668392e06a46b8c77_preview_featured.jpg" %}

#### Frame Mounting Bracket

The mounting bracket attaches to the frame sides with screws and provides holes for mounting the face plate.

{% include image.html file="frame_mounting_bracket.jpg" %}

{% include stl.html file="flap_frame_mounting_bracket.stl" thing=2722523 
   image="https://cdn.thingiverse.com/renders/14/33/bc/09/32/1481a6a28dd1a7367791669bd501afb1_preview_featured.jpg" %}

#### Lever Mount

The lever mount secures the flap lever to the potentiometer.

I used a spring between the potentiometer nut and the lever and a second adjustable spring-tensioned screw to keep lateral pressure on the handle in all positions. The curve in the mount allows the handle to move laterally without binding.

{% include image.html file="flap_lever_mount.jpg" %}

{% include stl.html file="flap_lever_mount.stl" thing=2722523 
   image="https://cdn.thingiverse.com/renders/51/c7/4c/03/06/ed70e91f2c6651211cf98dc2dad79c79_preview_featured.jpg" %}

### Face Plate

The face plate is 3d printed using white PLA, painted black, and then laser engraved. The face plate is used to mount the assembly to the panel and is attached to the frame mounting bracket with pan head screws.

{% include image.html file="flap_faceplate.jpg" %}

{% include stl.html file="flap_faceplate.stl" thing=2722523 
   image="https://cdn.thingiverse.com/renders/ff/c9/55/7f/e7/4c19827c4beaa1f0516fe072094acf4f_preview_featured.jpg" %}

I used blue painters tape (didn't have any paint the correct color) to indicate the maximum flap speed and I laser engraved the tape and lettering in a single pass.

{% include svg.html file="flap_faceplate.svg" %}

### Flap Handle

The flap handle is a 3d printed from white PLA and threads onto the flap lever.

{% include stl.html file="flap_handle.stl" thing=2722523 
   image="https://cdn.thingiverse.com/renders/75/ec/23/f2/10/ca375c817be3c2989422022492f4cd9d_preview_featured.jpg" %}

### Position Indicator

The flap position indicator is 3d printed from white PLA and is attached to the servo motor.

{% include stl.html file="flap_position_indicator.stl" thing=2722523 
   image="https://cdn.thingiverse.com/renders/8e/03/01/43/b1/db887af09c93a93bba9b7eea1f1b649a_preview_featured.jpg" %}

## Cabin Heat/Air Knobs

Work in progress.

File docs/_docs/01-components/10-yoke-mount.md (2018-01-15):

---
title: Yoke Mount
permalink: /docs/yoke-mount/
toc: false
---
# Yoke Mount

Work in progress

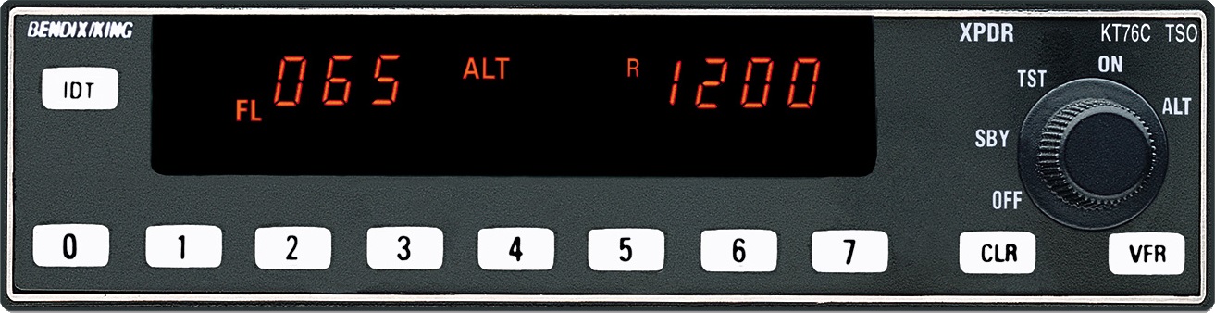
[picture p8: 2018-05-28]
parts/avionics/bendix-king-kt-76c/p-KT76C-zoom.jpg

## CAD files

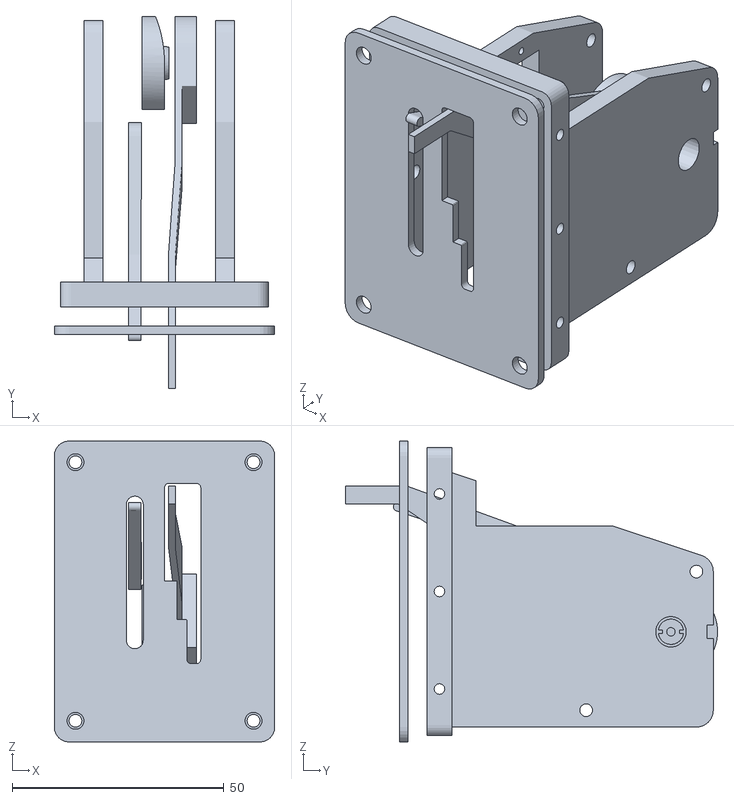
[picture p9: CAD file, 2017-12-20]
parts/flap-control-panel/flap_assembly_preview.stl
52.0 x 87.8 x 71.0

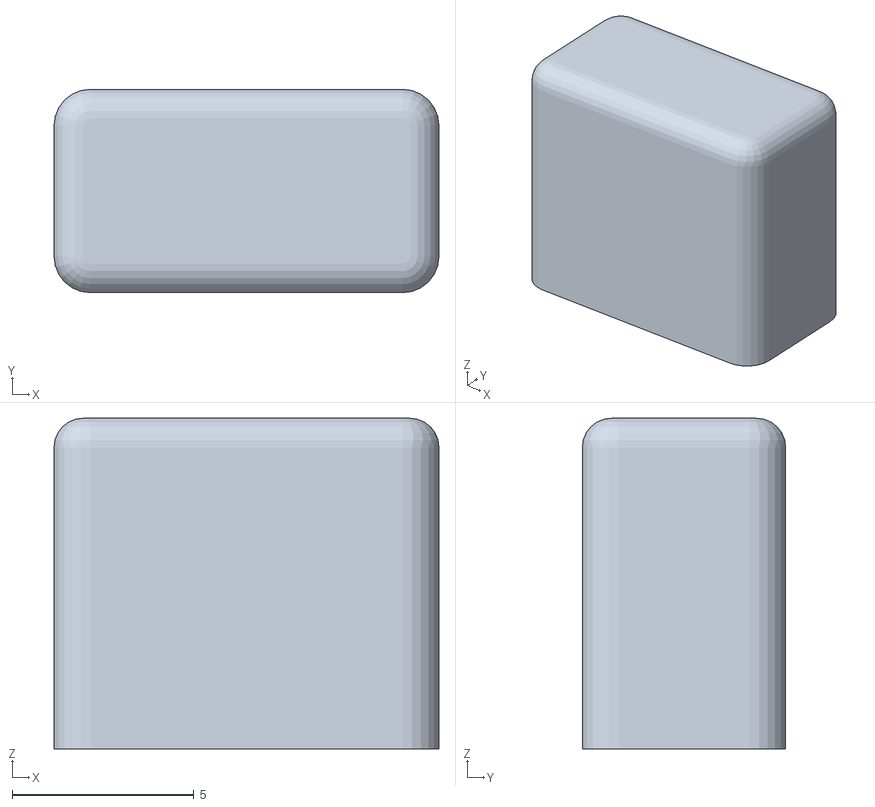
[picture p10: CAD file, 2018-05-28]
parts/avionics/bendix-king-kt-76c/button.stl
10.6 x 5.60 x 9.10

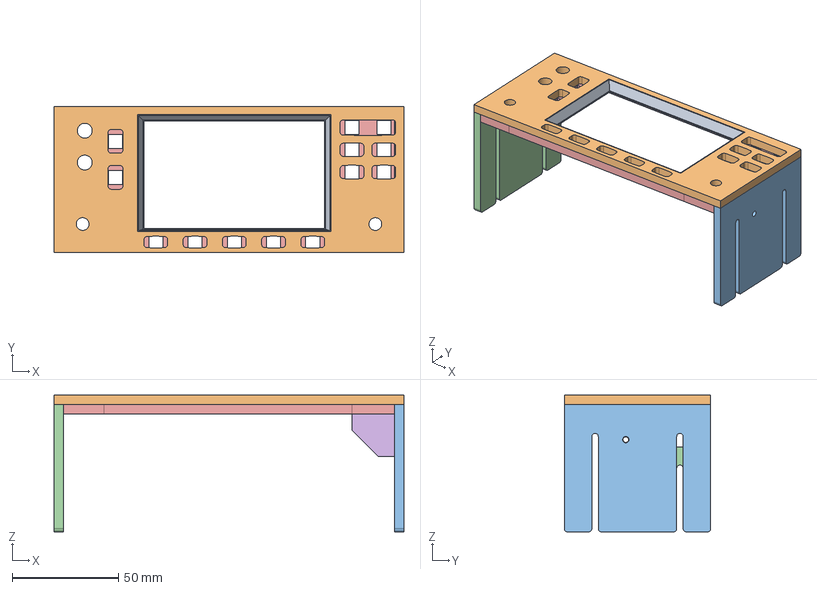
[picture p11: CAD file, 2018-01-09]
parts/avionics/garmin-gns-430/garmin_gns_430.FCStd
165.0 x 69.0 x 64.5 mm
Common (bezel)
Pad (faceplate)
Pad (panel right bracket)
Pad (panel left bracket)
Pad (panel hardware mount)

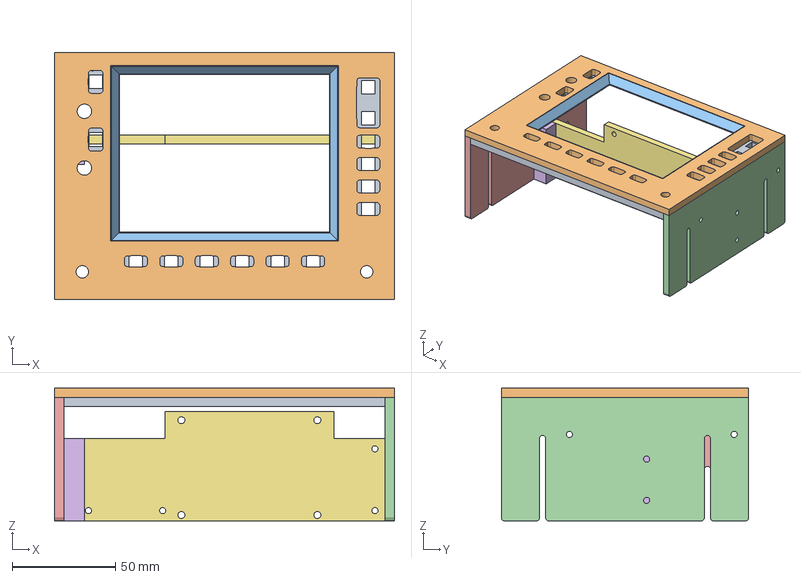
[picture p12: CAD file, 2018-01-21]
parts/avionics/garmin-gns-530/garmin_gns_530.FCStd
165.0 x 120.0 x 64.5 mm
Pad (hardware mount)
Pad (faceplate)
Pad (panel right bracket)
Pad (panel left bracket)
Pocket (display electronics mount block holes side)
Pad (display electronics mount)

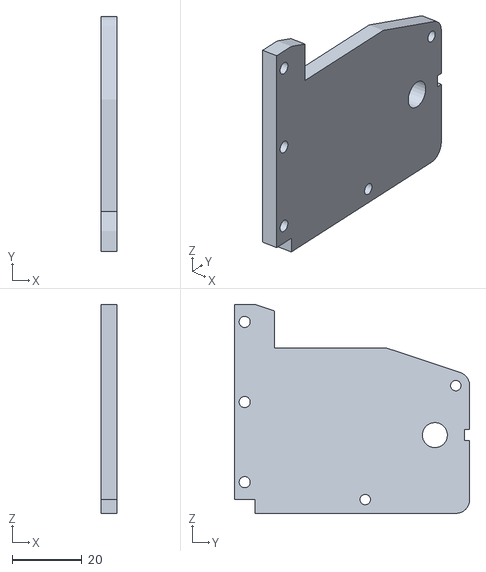
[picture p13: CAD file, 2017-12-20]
parts/flap-control-panel/flap_frame_right.stl
4.50 x 67.6 x 60.0

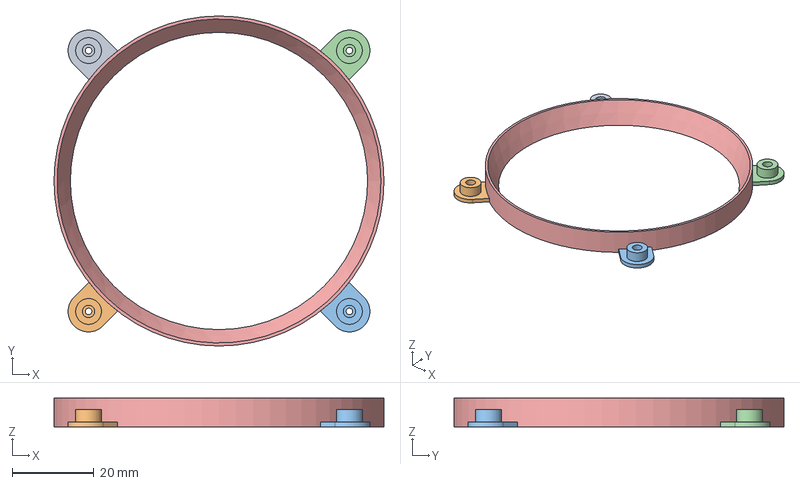
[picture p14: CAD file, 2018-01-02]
parts/instrument-panel/bezel_large.FCStd
80.5 x 80.5 x 7.00 mm
Pocket (tab threads)
Tab (bottom left)
Tab (bottom right)
Tab (top right)
Ring Chamfered

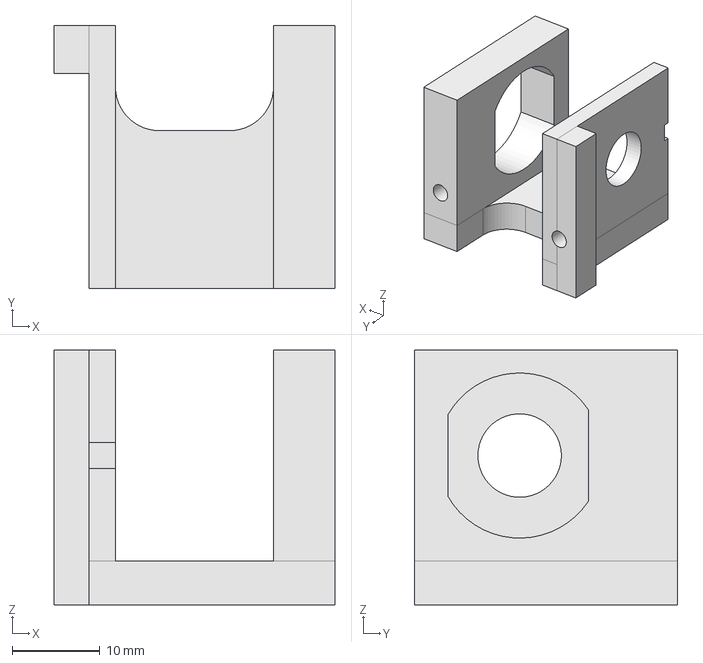
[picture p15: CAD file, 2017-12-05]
parts/key-switch/key_switch.FCStd
32.0 x 30.0 x 29.0 mm

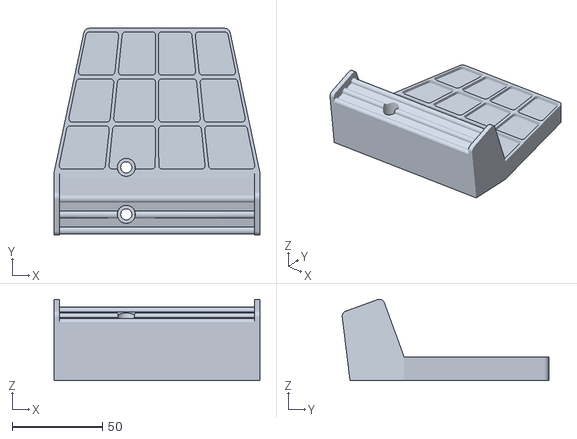
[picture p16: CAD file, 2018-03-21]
parts/rudder-pedals/rudder_pedal_right.stl
114.0 x 114.3 x 45.0

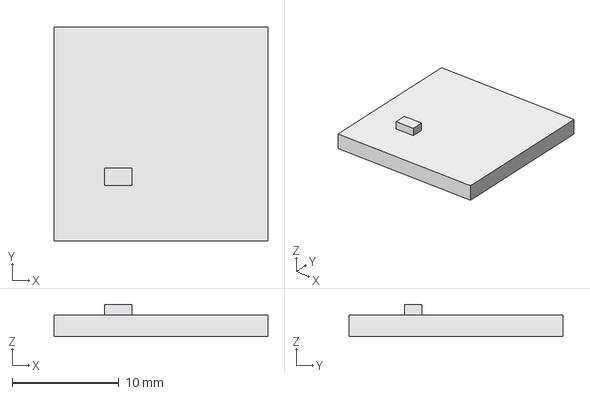
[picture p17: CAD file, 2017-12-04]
parts/switch-panel/fuse_button.FCStd
20.0 x 20.0 x 3.00 mm

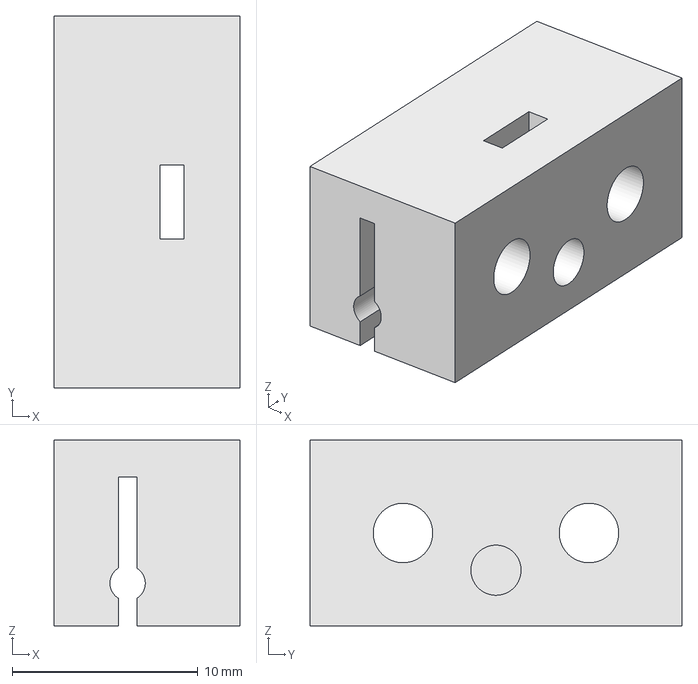
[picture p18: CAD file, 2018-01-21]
parts/throttle-mixture-panel/cable_clamp.FCStd
10.0 x 20.0 x 10.0 mm

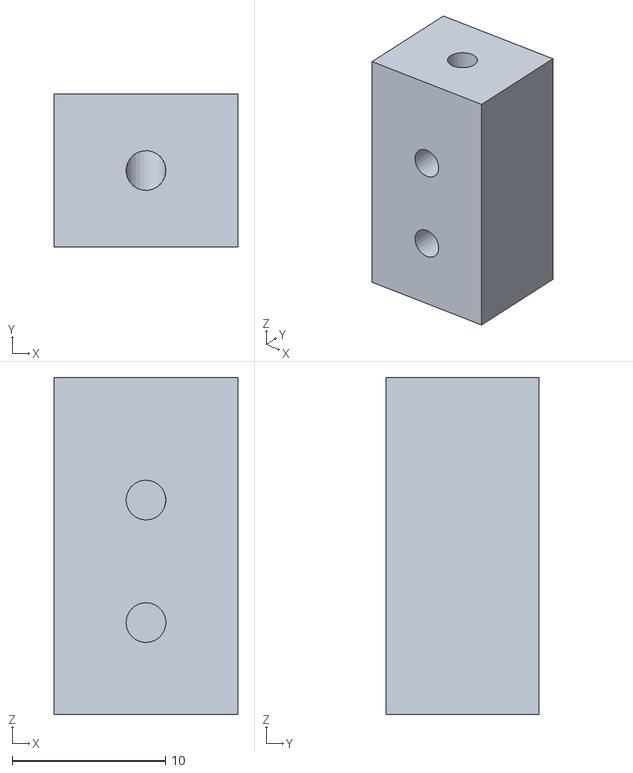
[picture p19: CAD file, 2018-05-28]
parts/avionics/bendix-king-kt-76c/front_bracket.stl
12.0 x 10.0 x 22.0

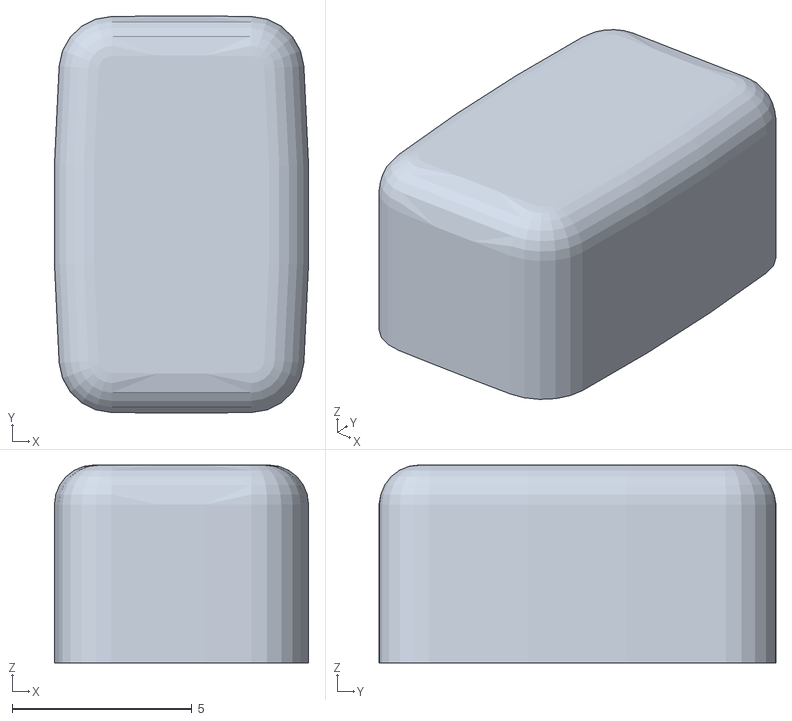
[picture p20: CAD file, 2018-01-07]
parts/avionics/garmin-gns-430/button_medium_vertical.stl
7.06 x 11.0 x 5.50

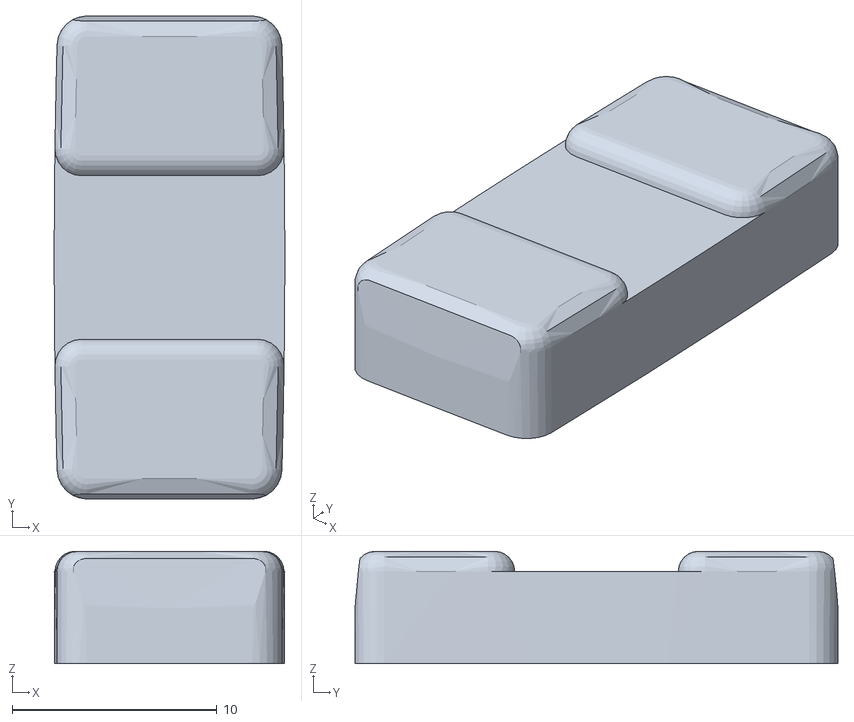
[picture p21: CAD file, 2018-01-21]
parts/avionics/garmin-gns-530/button_zoom.stl
11.3 x 23.6 x 5.50

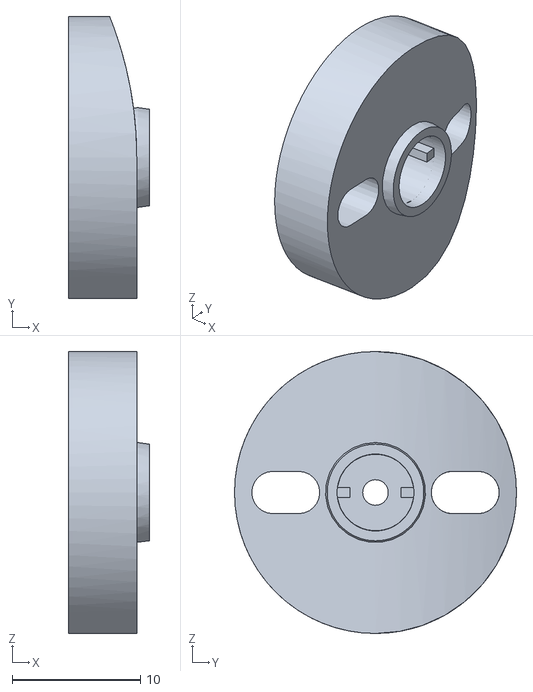
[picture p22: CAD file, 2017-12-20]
parts/flap-control-panel/flap_lever_mount.stl
6.35 x 22.0 x 22.0

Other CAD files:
parts/flap-control-panel/flap_assembly.FCStd
parts/instrument-panel/bezel_small_clock.stl
parts/rudder-pedals/rudder_pedal_left.stl
parts/switch-panel/fuse_button_guide.stl
parts/avionics/bendix-king-kt-76c/bendix_king_kt_76c.FCStd
parts/avionics/bendix-king-kt-76c/bezel.stl
parts/avionics/bendix-king-kt-76c/side_bracket.stl
parts/avionics/garmin-gns-430/button_medium.stl
parts/avionics/garmin-gns-430/button_small.stl
parts/avionics/garmin-gns-430/button_zoom.stl
parts/avionics/garmin-gns-430/display_bezel.stl
parts/avionics/garmin-gns-430/display_clip.FCStd
parts/avionics/garmin-gns-430/display_clip.stl
parts/avionics/garmin-gns-430/frame_mount_bracket.stl
parts/avionics/garmin-gns-430/knob.FCStd
parts/avionics/garmin-gns-430/knob_inner.stl
parts/avionics/garmin-gns-430/knob_outer.stl
parts/avionics/garmin-gns-430/knob_volume.FCStd
parts/avionics/garmin-gns-430/knob_volume.stl
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

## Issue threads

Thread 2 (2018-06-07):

Back of Instrument Panel Images

acirinelli, 2018-06-07:
Thanks for putting this together! I'm using your 3D printed bezels. I was wondering if you have any images of the backside of the panel (encoder wiring) prior to installing over monitor?

mccluress, 2018-06-09:
I agree!  It looks great but I am unsure if you made all the cuts/routing from the back to be able to mount them and still have the area to screw them in.  I really want to use your designs for this...maybe add a manifold pressure gauge so I can go between a couple of aircraft.  It wouldn't be "accurate" for other aircraft but Id have all the gauges plus some that I need.

acirinelli, 2018-06-09:
You can always tweak the design and just print another bezel for the extra gauge. I made some adjustments to my layout a s plan to do a different throttle set up so i can fly twins as well.

mccluress, 2018-06-11:
Hey,
      I'm sure this is a silly question but I was hoping you could help me out.  With ardsimx, what are you using for the encoders on the Directional Gyro?  The left one should turn the card to align it with the compass and the right should be a heading bug.  I see only one encoder spot for directional gyro in ardsimx.  Thanks for any help you can offer.  Looking to get this thing off the ground when I get back home from deployment.

    On ‎Sunday‎, ‎June‎ ‎10‎, ‎2018‎ ‎01‎:‎24‎:‎20‎ ‎AM, Anthony Cirinelli <notifications@github.com> wrote:

Reopened #2.

—
You are receiving this because you commented.
Reply to this email directly, view it on GitHub, or mute the thread.

acirinelli, 2018-06-12:
@mccluress I haven't gotten that far yet, but I would guess you just add another heading sync and then modify the data.cfg file to point to rhe_DG_SYN. Will have to dive in a bit more to figure out if that's correct and up/down, but it shouldn't be too difficult.

allanglen, 2018-06-15:
@acirinelli I'll get some photos posted of the back of the panel that shows the wiring. I used a dremel router bit to route channels for the wires. Everything fits within the depth of the plywood (plus the depth of the thin tabs for the bezels which match the depth of the metal bezel around the display). This allows the bezels to fit flush against the surface of the display.

I've been meaning to get those details posted but it requires some disassembly. Thanks for prompting me. I'll try to get something posted this weekend.

allanglen, 2018-06-15:
@mccluress ArdSimX provides pre-configured parameters for convenience but you can connect to any X-Plane dataref. I haven't posted my config file as I was hoping to upgrade to ArdSimX 2 (aka SimVimCockpit) before doing that.

I'm actively using my panel now and busy with my real world flight training so I probably won't upgrade to SimVimCockpit any time soon. I'll go ahead and get my ArdSimX config file posted so you can see how everything connects.

mccluress, 2018-06-15:
Thanks!  I appreciate it!  I am going to be building a similar instrument panel and your transponder soon.  My com/nav2, DME, and ADF are all LCDs but you did such a great job on that transponder, I'm just gonna steal yours!  Awesome work!  I just cant figure out how you get the XPDR to say "ON" or whatever else besides the transponder code so I cant wait to see your files!  Good luck with your real world training!  Flying is a blast!  Ill probably get into my commercial when I get back home!

    On ‎Friday‎, ‎June‎ ‎15‎, ‎2018‎ ‎02‎:‎34‎:‎44‎ ‎PM, Allan Glen <notifications@github.com> wrote:

@mccluress ArdSimX provides pre-configured parameters for convenience but you can connect to any X-Plane dataref. I haven't posted my config file as I was hoping to upgrade to ArdSimX 2 (aka SimVimCockpit) before doing that.

I'm actively using my panel now and busy with my real world flight training so I probably won't upgrade to SimVimCockpit any time soon. I'll go ahead and get my ArdSimX config file posted so you can see how everything connects.

—
You are receiving this because you were mentioned.
Reply to this email directly, view it on GitHub, or mute the thread.

acirinelli, 2018-06-17:
Awesome 👏
those look super helpful, thank you!

acirinelli, 2018-06-17:
My gauge panel work in progress from today. I’m using a 21.5”, so my layout is a little different.
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

acirinelli, 2018-08-04:
@allanglen Would you be willing to add your data config file for reference? I cannot figure out how to adjust the TAS indicator with the encoder

the1andonlyalt, 2018-10-06:
Hi Allen.  Fanstastic work BTW.  This may seem like a silly request.  Any photos of the back of the GNS430?  Like to see your wiring schematic.  I'm planning on building a dumbed down version of yours.  Rough scale and may add the external display till later.  My first goal is to get off the mouse during flying approaches while I work on my Instrument rating.  I expect I may just punch in some buttons and a couple of encoders. hooked to an arduino.   Like to see more of the background build specifics on yours.

Alt

the1andonlyalt, 2018-10-07:
And Allan not en.  sorry... i blame either spellcheck or problem lies between keyboard and chair.

allanglen, 2019-06-29:
There are rear photos here: https://cessna172sim.allanglen.com/docs/avionics/garmin-gns-430/

The buttons and encoders wire to an Arduino. I don't have a schematic of that layout but you can learn more on the ArdSimX site (http://simvim.com/archive/asx_wire.html)

Closed 2019-06-29.

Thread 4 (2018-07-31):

trim wheel documentation

timothy-hart, 2018-07-31:
any chance we could see some more details around the trim wheel?  thanks

adipinto, 2018-08-12:
I too would be interested in seeing more details about the motorized trim wheel.
Thank you for your amazing job and for your time!

acirinelli, 2018-12-21:
@allanglen I was just about to ask the same question. Curious what stepper motor & controller you used and how it's assembled. I just ordered the 3D printed wheel.

allanglen, 2019-06-29:
Apologies for the very slow response on this. I have moved and all of my equipment and the simulator are currently in storage. As a result I haven't had a chance to continue working on this.

The parts for the trim wheel were scavenged from a broken laser printer so they are all non-standard components. The motor is a DC motor with a rotary encoder. I have not completed the programming yet for driving the motor in response to the autopilot in the sim.

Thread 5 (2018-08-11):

data.cfg file

acirinelli, 2018-08-11:
@allanglen Would you be willing to share your data config file for reference? I cannot figure out how to adjust the TAS indicator with the encoder. I did get it moving erratically with the "laminar/c172/knob_TAS" custom ref, but not correctly. Did you get yours to move correctly?

mccluress, 2018-09-30:
Did you get the 7 segment transponder to work? Mine comes up all 8s

acirinelli, 2018-10-01:
@mccluress I'm using saitek radios, so I don't really have that issue.

afshinjaam, 2018-12-05:
Hello allanglen
. I'm asking for help
I am a computer engineer from Iran. I want to create a 172 Sesena simulator.
If you start from start to build.
I need your help. Thanks
amoghaddam.a@gmail.com
00989156957768
afshin zabihi moghadam

allanglen, 2019-06-29:
Apologies for the very slow response on this. I have moved and all of my equipment and the simulator are currently in storage.

I didn't have any problems with the encoder moving erratically but that may depend on which version or ArdSimX you are using as there have been several changes to how encoder acceleration and smoothing are handled.

Austinthemighty, 2020-10-03:
So for erratic encoder movement you need to add a 10k resistors to the 5v and signal wire on the multiplexer

acirinelli, 2020-10-05:
> So for erratic encoder movement you need to add a 10k resistors to the 5v and signal wire on the multiplexer

That really depends on your system, wire lengths, etc. For anyone reading this in the future, it's best just to read all the documentation on SimVim's website.

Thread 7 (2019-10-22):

Audio Panel stl files

0sander, 2019-10-22:
Hi @allanglen
First of all thank you so much for your documentation. I am in the process of building a home cockpit based on the 172 that I am flying in real live. I already completed the GNS 430 and would like to add GMA 340 as well. Is there any chance that you upload the stl files for the 340 as well?
Thanks!

Austinthemighty, 2019-11-08:
Im actually in the process of building one of those right now, its not complete, but I will share what I have, I haven't actually made anything for it except the buttons, the buttons hold a 3 mm led and all the hardware is the same that is used in other projects
 https://www.icloud.com/iclouddrive/0lrEMFSld24MRmgrzQG1jlH8A#AudioPanel

Skidroq, 2019-11-18:
Allan, thanks so much for all your work. I am starting the process and have done the transponder panel. I have found a laser cutter to do the faceplates, they will look a bit nicer than from my 3d printer and they can be engraved right away then as well.

Austin, great work on the audio panel! Do you happen to have the faceplate as a dxf file yet. I see all the other parts are in that format. I was hoping to get it laser cut along with the GPS and transponder panels at the same time if you did have that. Either way thanks for your work on that thus far.

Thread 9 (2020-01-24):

Updates

Redthered, 2020-01-24:
Hello I am trying to build this but a lot of the links don’t work or link to items that you can no longer purchase. Are you going to update the repository anytime soon?

Redthered, 2020-01-24:
Also ware can I find wiring diagrams

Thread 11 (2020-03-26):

Upgrade to SimVim Cockpit

dertin, 2020-03-26:
Hi @allanglen
It would be very interesting to see the updated arduino code. I would like to collaborate on the project.

fursov-me, 2020-03-26:
i too

acirinelli, 2020-04-05:
I'm interested in this as well, I'll be scrapping my old sim to build new one and attempting to upgrade to SimVim. Happy to contribute to the git repo when/if helpful.

Austinthemighty, 2020-07-18:
have you had any problems with multiple rotary encoders on one multiplexer? for some reason when I turn one, one or more will start spazing out and rotate in x-plane

acirinelli, 2020-07-19:
> have you had any problems with multiple rotary encoders on one multiplexer? for some reason when I turn one, one or more will start spazing out and rotate in x-plane

I ran into a few issues during my build with similar problems where inputs were spazing out. It's typically either bad wiring (a loose S0-S3 wire for example) or a bad MP. I had two MP's out of about 8 not work correctly. Wasted hours trouble shooting and then when I swapped out the board everything was fine. Double check your MP wiring first.

acirinelli, 2020-07-19:
For the record here, I scrapped all my ArdSim stuff and rebuilt everything. I used SimVim and multiplexers. All necessary information is available from SimVim.com .. really no need for explanations here on how to do that.

Austinthemighty, 2020-07-23:
ok thanks I guess I got a bad batch of multiplexers than

acirinelli, 2020-07-23:
> ok thanks I guess I got a bad batch of multiplexers than

Check your grounds too. I had a ground come unplugged the other day and things were going haywire.

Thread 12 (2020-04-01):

GNS 430 Hardware Plate Dimensions

acirinelli, 2020-04-01:
The [uxcell mini push buttons](https://www.amazon.com/gp/product/B00OK476IG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) have a dimension of 7mm (~0.273 in) and I cannot get them to fit in a 3D printed hardware plate which has dimensions closer to 0.25 in when finished. I tried modifying the cad file to 0.27 in and it still prints closer to 0.26 in. I may up the size again another 10th and see how it prints, however...

The SVG file has dimensions of 0.2618 in. When this part was laser cut, did the 7mm push buttons fit snug in that hole and was that the actual cut dimension? Is it possible that the dimensions changed slightly since you purchased the push buttons?

I don't want to pay for laser cut parts that may not work (which is why I am trying to print them). Any feedback would be helpful.

acirinelli, 2020-04-05:
For anyone interested, I increased the button dimensions to 0.28 which printed at about 0.269-0.272. This may vary printer to printer. The buttons fit snug and I had to sand a few holes a little bit for nice smooth fit and button press. Then I used dabs of hot glue on the back side to ensure they would stay in place.
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

acirinelli, 2020-04-07:
I also added a cross beam piece to support 2 multiplexers for all the switches in the unit.
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

acirinelli, 2020-04-20:
I used the [Propwash dual encoder](https://www.tindie.com/products/propwashsim/dual-concentric-encoders-with-switch-kit/) and the outer/inner buttons did not fit, very loose and just fell off. The dimensions of the encoder shafts were fairly different than the model dimensions. I revised the parts and stl files, but I am unable to share here. Just an FYI for anyone trying to print with this encoder, it may not work for you.

JTRACKER, 2020-04-20:
Does anyone have the part number for the encoder being used?

acirinelli, 2020-04-20:
> Does anyone have the part number for the encoder being used? I don't want to pay >$20 for a PCB/encoder/knobs - if I don't have to.

No, but here is an [updated link](https://www.propwashsim.com/store/dual-encoder-kit) to a cheaper version direct from Propwash. Best bet is to reach out to them.

Austinthemighty, 2020-07-18:
I got those ones from prop wash but struggled to get them to sit right, patently they have a square hole, which made it quite difficult.

acirinelli, 2020-07-19:
> I got those ones from prop wash but struggled to get them to sit right, patently they have a square hole, which made it quite difficult.

I believe you are referring to the notch on them. I took a metal file to that and filed it off. Sits flush on the back side into a round hole.

Austinthemighty, 2020-10-03:
So I did remove the notch on mine but the problem was that the threads were not long enough on the encoder to fit through the acrylic

rubicon0007, 2023-09-29:
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

I had the same issue with the 530. I've currently got 3 full prints and two half prints before finding the proper button size and spacing. My printer does a great job printing smooth lines without excessive squish or any other problems so i know it had to be an issue between printing and laser cutting. My buttons are 7mm as well and increased the button holes to 7.2mm using tinkercad. Finally, I've made enough progress to actually get good results. I'll provide a thingiverse link later with the edited STL so more people dont run into the same issue. I could not find a proper file that would allow for the buttons to fit the right way. NO WAY was i going to file out all of these holes!

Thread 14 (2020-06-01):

Small instrument size

JessT2810, 2020-06-01:
What size hole saw bit do i need for the small instruments( fuel flow and oil temp) so the 3D printed bezel fits.

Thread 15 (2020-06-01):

Router Template

JTRACKER, 2020-06-01:
Has anyone used the 3d printed router Template for the I strumebt bezel?

I am curious how it's used.

JJMalette, 2020-06-02:
If a 'strumebt bezel' is a bezel that accommodates one or more encoders, then the template is used with a router and a 'flush' bit to remove the material (wood, plastic) to make space to install an encoder. I've used it to install encoders required in a C172 open cockpit which I completed last year. Without Allen's printed 3D files for printing the bezels, I think I'd still be trying to learn 3D software rather than building the cockpit.

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

JTRACKER, 2020-06-02:
That's beautiful what you have built and thank you for the reply.

I will certainly be printing all the bezels and understand what a router
template "should" be used for, but cannot see how the printed router
template supplied, was to be used.

Sorry if I'm sounding so dumb, but maybe I will just need to print it and
try to figure it out.

Thanks again for the reply.

JT

On Tue., Jun. 2, 2020, 10:41 a.m. JJMalette, <notifications@github.com>
wrote:

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

JJMalette, 2020-06-02:
Hi JT,

Within the next couple of days, I’ll send you one or more pictures that will hopefully give you a hint or two! Please be patient, I’m undergoing chemotherapy treatments which cause me to be useless on some days. I have cancer of the bladder which many people have had and are today near top-shape. I remain positive and keep busy with fliightsim projects including helping others realize their dream.

All the best, JJ

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

JTRACKER, 2020-06-02:
I would prefer you rest and get well.  My sister went through years of
chemo and am familiar with the exercise and difficulties of cancer - from
the observer side.

Please take care of yourself and don't worry about my inquiry.

JT

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

JJMalette, 2020-06-02:
You’re very kind JT. But luckily I do have good days and it’s on those days that I enjoy life by engaging in worthwhile things for me and others.

Sent from Mail for Windows 10

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

JTRACKER, 2020-08-30:
Good Day Sir,

How is life treating you and how are you managing your treatment?  I hope
things are doing well and the chemo is not giving too many terrible side
effects.

Hopefully you will be able to get back to normal as soon as possible.

Regards,

Jeff Thompson

On Tue, Jun 2, 2020 at 12:48 PM Jeffrey Thompson <sattracker@gmail.com>
wrote:

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

grantges, 2021-12-02:
@JTRACKER

The router template is setup so that you can place it into the 3 1/8" hole you have cut into your 1/4 board. Then use a flush trim bit in your router so that it follows the inside of the router template.

Here is a video for using Flush Trim bits with a router that might help:
https://www.youtube.com/watch?v=enW2pabgwYw

Good luck!

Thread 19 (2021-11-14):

Laser engraved button

Pietrogramma, 2021-11-14:
Hi Allanglenn, for first compliment for your great work and thanks for sharing it. I would construct the avionics of the Cessna C172, following your blog and your instruction.
I have a stupid request for you: can you explain how You have proceeded for engrave the buttons?
You printed they, then coloured black and finally you engraved with a laser, but how you found the exactly position where put the button printed and coloured?
You have realizated a jig for found the exact position or you have proceeded to sight,
Thanks and sorry for my bad english.

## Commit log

2017-12-04 Add README for the switch panel
2017-12-04 Add switch panel svg file
2017-12-04 Add fuse documentation
    [fuse_button.FCStd, fuse_button.stl, fuse_button_guide.stl]
2017-12-05 Improve switch panel documentation
    [key_switch.FCStd, key_switch.stl]
2017-12-05 Publish instrument panel documentation
    [bezel_annunciator.FCStd, bezel_annunciator.stl, bezel_clock_button.FCStd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]
2017-12-18 Document throttle and mixture panel
    [rheostat_knob_inner.stl, rheostat_knob_outer.stl, rheostat_knobs.FCStd]
2017-12-18 Add README for yoke mount
2017-12-18 Add throttle/mixture knob models, add Thingiverse links
    [mixture_button.stl, mixture_knob.FCStd, mixture_knob.stl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]
2017-12-18 Add link to screws
2017-12-20 Add flap control documentation and artifacts
    [flap_assembly.FCStd, flap_assembly_preview.stl, flap_faceplate.stl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]
2017-12-30 Publish WIP of Garmin GNS 430
    [avionics_mount_bracket.stl, bezel.stl, button_medium.stl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]
2018-01-02 Exported stl for the large bezel was incorrect
    [bezel_large.FCStd, bezel_large.stl]
2018-01-07 Small update to the GPS buttons (0.05 mm wider hole) to make them easier to mount on the push buttons
    [button_medium.stl, button_medium_vertical.stl, button_small.stl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]
2018-01-07 Add a note about the frame
2018-01-09 Renamed 'avionics mounts' to 'frame mounts' for clarity
    [frame_mount_bracket.stl, garmin_gns_430.FCStd]
2018-01-12 Update Readme to match renamed frame mounts
2018-01-15 Reorganize repo, remove embedded docs and point to project site instead
    [bezel.stl, bezel_annunciator.FCStd, bezel_annunciator.stl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]
2018-01-17 Rename directory
    [bezel.stl, bezel_annunciator.FCStd, bezel_annunciator.stl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]
2018-01-21 Directory renames and publishing of the Garmin GNS 530
    [bezel.stl, bezel_annunciator.FCStd, bezel_annunciator.stl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]
2018-01-24 Correct the stl file names
2018-03-21 Add rudder pedal documentation
    [rudder_pedal_left.stl, rudder_pedal_right.stl, rudder_pedals.FCStd]
2018-03-24 Switch to GTM
2018-05-28 Added documentation for the Bendix King transponder, updated status
    [bendix_king_kt_76c.FCStd, bezel.stl, button.stl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]
